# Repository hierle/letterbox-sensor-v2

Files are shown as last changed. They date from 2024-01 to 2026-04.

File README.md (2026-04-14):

# LoRaWan EU868MHz Letterbox Sensor v2
sensing letters in your letterbox via two infrared proximity sensors (HSDL9100),
sending out status via lora / lorawan, using RAK3172 (based on STM32WLE5CC) CPU/RF, powered by a CR2032 battery.

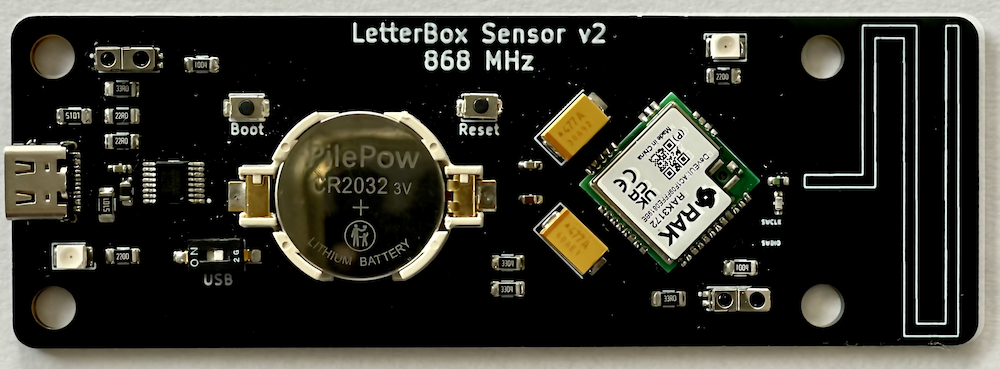
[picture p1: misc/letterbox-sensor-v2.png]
Lorawan letterbox sensor v2
<br>
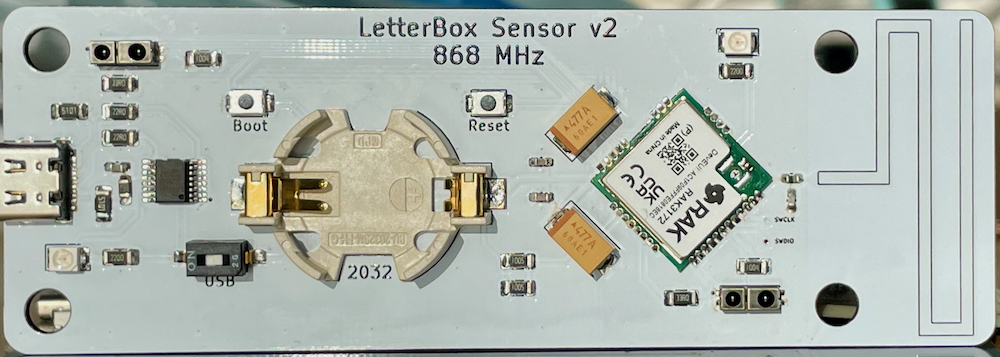
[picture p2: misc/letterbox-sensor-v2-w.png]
Lorawan letterbox sensor v2


This project was inspired by the heise ct briefkasten sensor project<br>
https://www.heise.de/ratgeber/IoT-Netz-LoRaWAN-Briefkastensensor-mit-hoher-Reichweite-selber-bauen-4417179.html<br>
https://github.com/jamct/radio-mailbox<br>
and is a direct successor of version 1: https://github.com/hierle/letterbox-sensor

Contents:
- ./PCB/ :                  kicad PCB files
- ./letterbox-sensor-v2/ :  lorawan letterbox sensor sketch
- ./misc/ :                 payload decoder, sample http integration cgi

An extended web ui by Peter is available here: https://github.com/pbiering/letterbox-sensor-web

A nice alternative software by Henrik, using Lora P2P mode is available here: https://github.com/HonkStonk/MightyMailbox

Compiled and flashed with ArduinoIDE with RAKWireless STM32 extensions

Features:
- using RAKWireless RAK3172 based on STM32WLE5CC
- deep sleep at (measured) 5uA including battery voltage divider and tantalium caps
- two proximity sensors HSDL9100
- USB-C interface for flashing and serial monitor, via FT230XS-R USB-UART
- onboard 868MHz PCB antenna after TI document http://www.ti.com/lit/an/swra227e/swra227e.pdf
- lorawan activation either ABP or OTAA
- battery voltage measurment thru voltage divider (2x 10MOhm)

Changes to v1:
- replaced ATTiny and RFM95 with RAK3172, much more CPU power and memory, much simpler code
- support for OTAA lorawan activation
- much simpler software stack, using ArduinoIDE with RAKWireless STM32 extensions and API usage
- added USB-C interface, no more special programming interface needed
- added second HSDL9100 for better physical letterbox coverage
- added two (optional) supporting tantalium caps for extended battery life
- removed temperature, as not easily avail on STM32WLE5CC / RAK API
- removed trimmers

BOM (digikey.de):

| Count | Part number | Description | Usage |
|---|---|---|---|
| 1 | RAK3172-8-SM-NI | CPU/RF-Lora  NO IPEX! | CPU/RF module |
| 2 | CS1213AGF260 | Tactile switch | Boot/Reset |
| 2 | HSDL-9100-021/024  | Proximity Sensor | Proximity sensors |
| 2 | CRGCQ1206F33R | RES 33 Ohm 1206 | Proximity sens LED | 
| 2 | CRGCQ1206F1M0 | RES 1M Ohm 1206 | Proximity sens diode |
| 1 | BU2032SM-FH-GTR | CR2032 COIN CELL HOLDER | Battery |
| 2 | TAJE477M010RNJ | CAP tant 470u | Battery supporting caps  |
| 1 | LQG18HN1N8S00D | IND 1.8NH 0603 | Antenna matching |
| 1 | GRM1885C1H2R7CA01D | CAP 2.7PF 0603 | Antenna matching |
| 3 | GRM188R72A104KA35D | CAP CER 0.1u 0603 | Suppressor caps |
| 2 | GRM188D71A106KA73D | CAP CER 10u 0603 | Suppressor caps |
| 1 | RAHUC31AUTR | USB-C connector | USB |
| 1 | FT230XS-R | FTDI USB Serial UART | USB UART |
| 1 | MI0805K601R-10 | Ferrite bead 0805 | USB power |
| 2 | AC1206FR-075K1L | RES 5.1k Ohm 1206 | USB power sens |
| 2 | CRGCQ1206F22R | RES 22 Ohm 1206 | USB lines |
| 1 | GRM188R72A104KA35D | DIP switch | Power switch USB/Battery |
| 2 | AA3528LSECKT/J4 | LED orange | Status/USB status |
| 2 | CRGCQ1206F220R | RES 220 Ohm 1206 | Status LEDs |
| 2 | RC1206FR-0710ML | RES 10M Ohm 1206 | Battery voltage measure  |

RAK3172 documentation:

https://docs.rakwireless.com/Product-Categories/WisDuo/RAK3172-Module/Overview/

How to compile:

Follow the instructions on<br>
https://docs.rakwireless.com/Product-Categories/WisDuo/RAK3172-Module/Quickstart/<br>
in short:<br>
- install ArduinoIDE from arduino.cc
- add the following URL to the boards manager URLs section in preferences:
https://raw.githubusercontent.com/RAKWireless/RAKwireless-Arduino-BSP-Index/main/package_rakwireless.com_rui_index.json
- install the "RAKwireless RUI STM32 Boards" from the Boards Manager
- select "WisDuo RAK3172 Evaluation Board" board
- on Mac you might need to install pyserial: sudo pip3 install pyserial
- on Linux you might need to install python3-pyserial
- connect the board, make sure it's powered on (DIP switch)
- select the corresponding serial port
- open the sketch folder
- adjust config.h and lorawan.h
- compile and flash

For configuration adjust config.h and lorawan.h

config.h:
- PERIOD: the time intervall you want the sensor to send it's data, in minutes, default is 30 minutes
- THRESHOLD: the threshold for the sensor readings (empty/full), can later be "overwritten" in e.g. HTML integration
- USE_OTAA: if true, OTAA will be used instead of ABP, so we do not have to worry about frame counters after reset / battery change
- DATARATE and TXPOWER: adjust to your needs, your packets should be reliably received, w/o wasting to much power
- see also the comments for each entry in config.h

lorawan.h:
- set your lorawan keys for either ABP or OTAA
- OTAA_APPEUI or JOINEUI is only needed to select a specific JOIN server, in private networks can be set to any value

Additional notes:
- you will need a *DATA* USB-C cable, a charging only cable will not work, as it's missing the data pins ;-)
- the DIP switch allows to power the device directly from USB, but when using the battery in production environment (letterbox), it should be switched off, not to waist power on the FT230 USB-UART chip

Letterbox sensor v2 lorawan payload package byte structure:

|byte| 0 |  1 2 | 3 4 | 5 6 | 7 |
|----|---|---|---|---|---|
| |0x00=empty|battery |sensor1|sensor2|threshold|
| |0xFF=full |voltage |raw |raw | |

Todos:
- read battery voltage and temperature from STM32
- see sections 3.18.1 and 3.18.3 in: https://www.st.com/resource/en/datasheet/stm32wle5c8.pdf

Have fun!

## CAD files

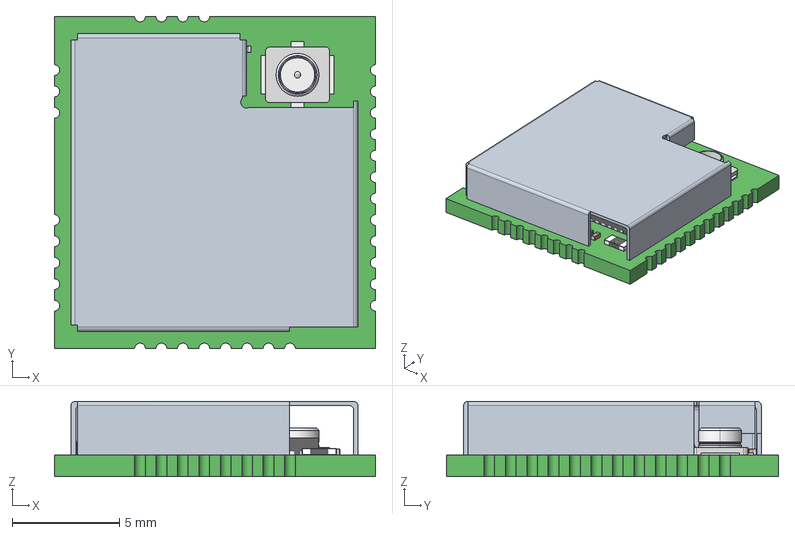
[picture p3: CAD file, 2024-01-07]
PCB/3D/RAK3172.step
15.0 x 15.5 x 3.51 mm
0201_SMD_Capacitor x 36
Extruded
R0201 x 7
RES_1005-0402 x 3
QFN48_7x7
NT2016SA
C0402 x 4
crystal_rtf2012
D030A-そ敖裔

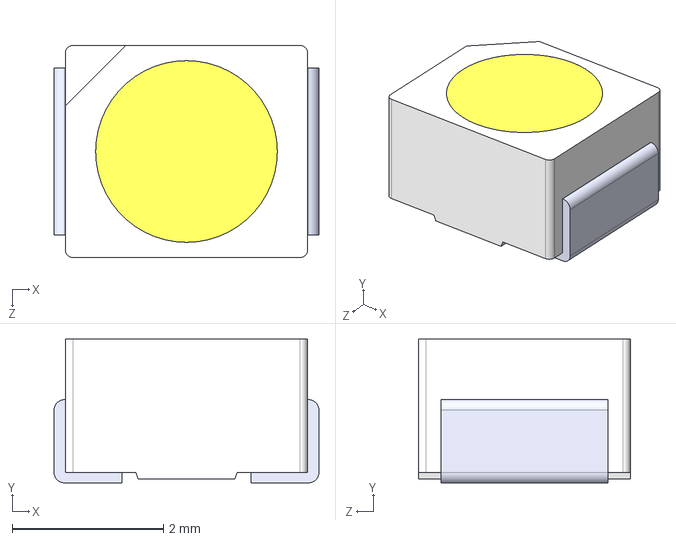
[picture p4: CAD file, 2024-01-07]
PCB/3D/OF-SMD3528WC--3DModel-STEP-269445.STEP
3.50 x 1.90 x 2.80 mm

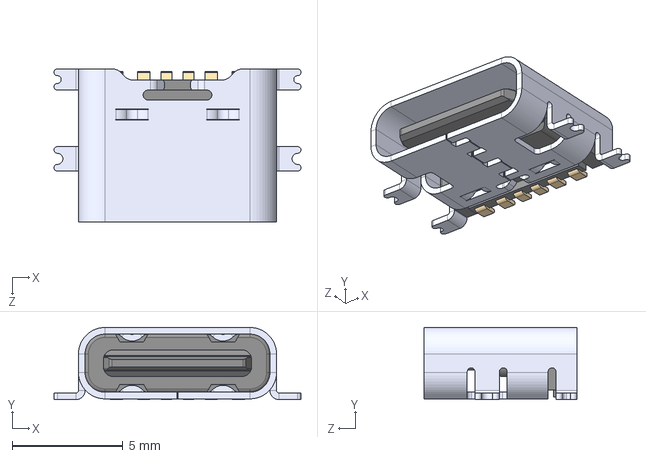
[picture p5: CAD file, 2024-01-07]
PCB/3D/USB4135-GF-A--3DModel-STEP-269445.STEP
11.1 x 3.25 x 6.90 mm

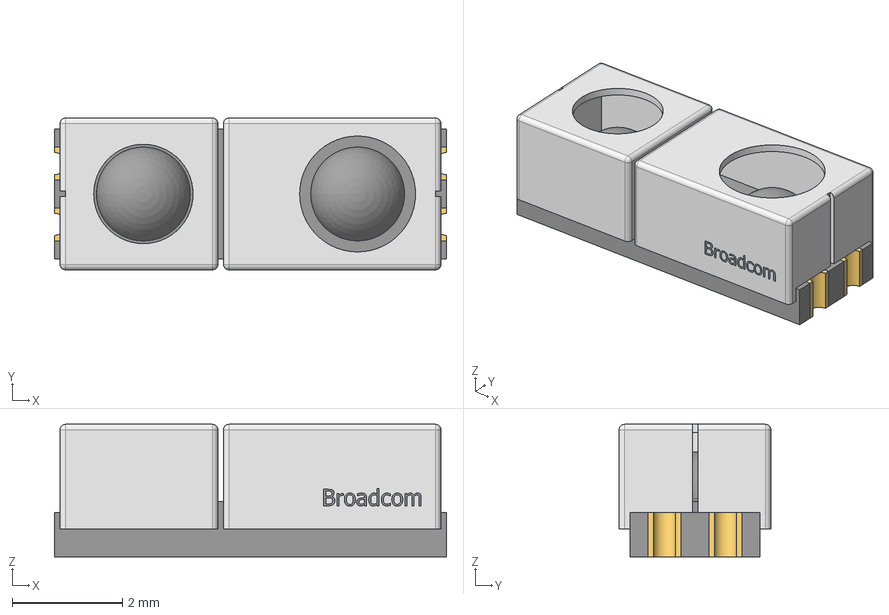
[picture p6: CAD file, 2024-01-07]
PCB/3D/Broadcom_-_HSDL-9100-021.step
7.10 x 2.75 x 2.40 mm
base
leds
terminals
name

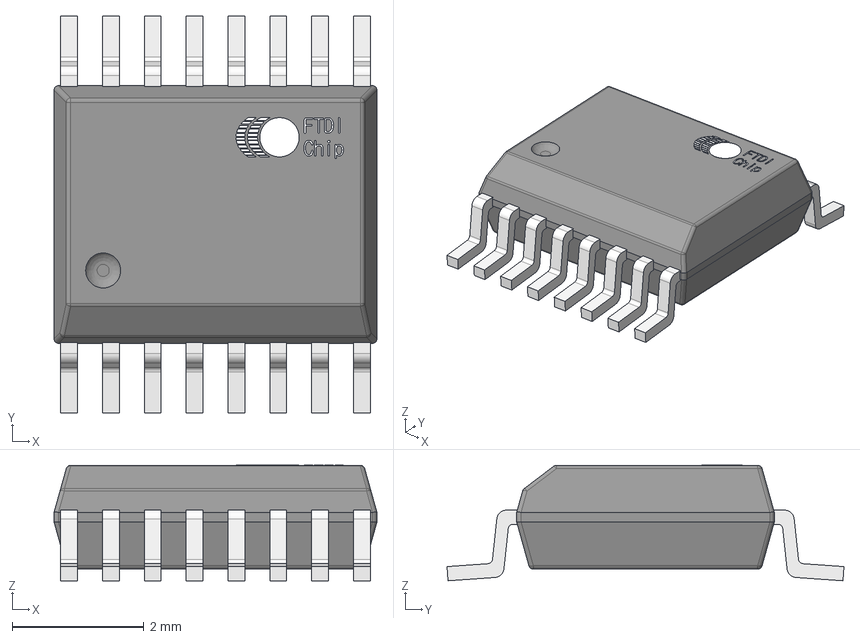
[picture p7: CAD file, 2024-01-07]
PCB/3D/FTDI_-_FT230XS-R.step
4.90 x 6.02 x 1.75 mm

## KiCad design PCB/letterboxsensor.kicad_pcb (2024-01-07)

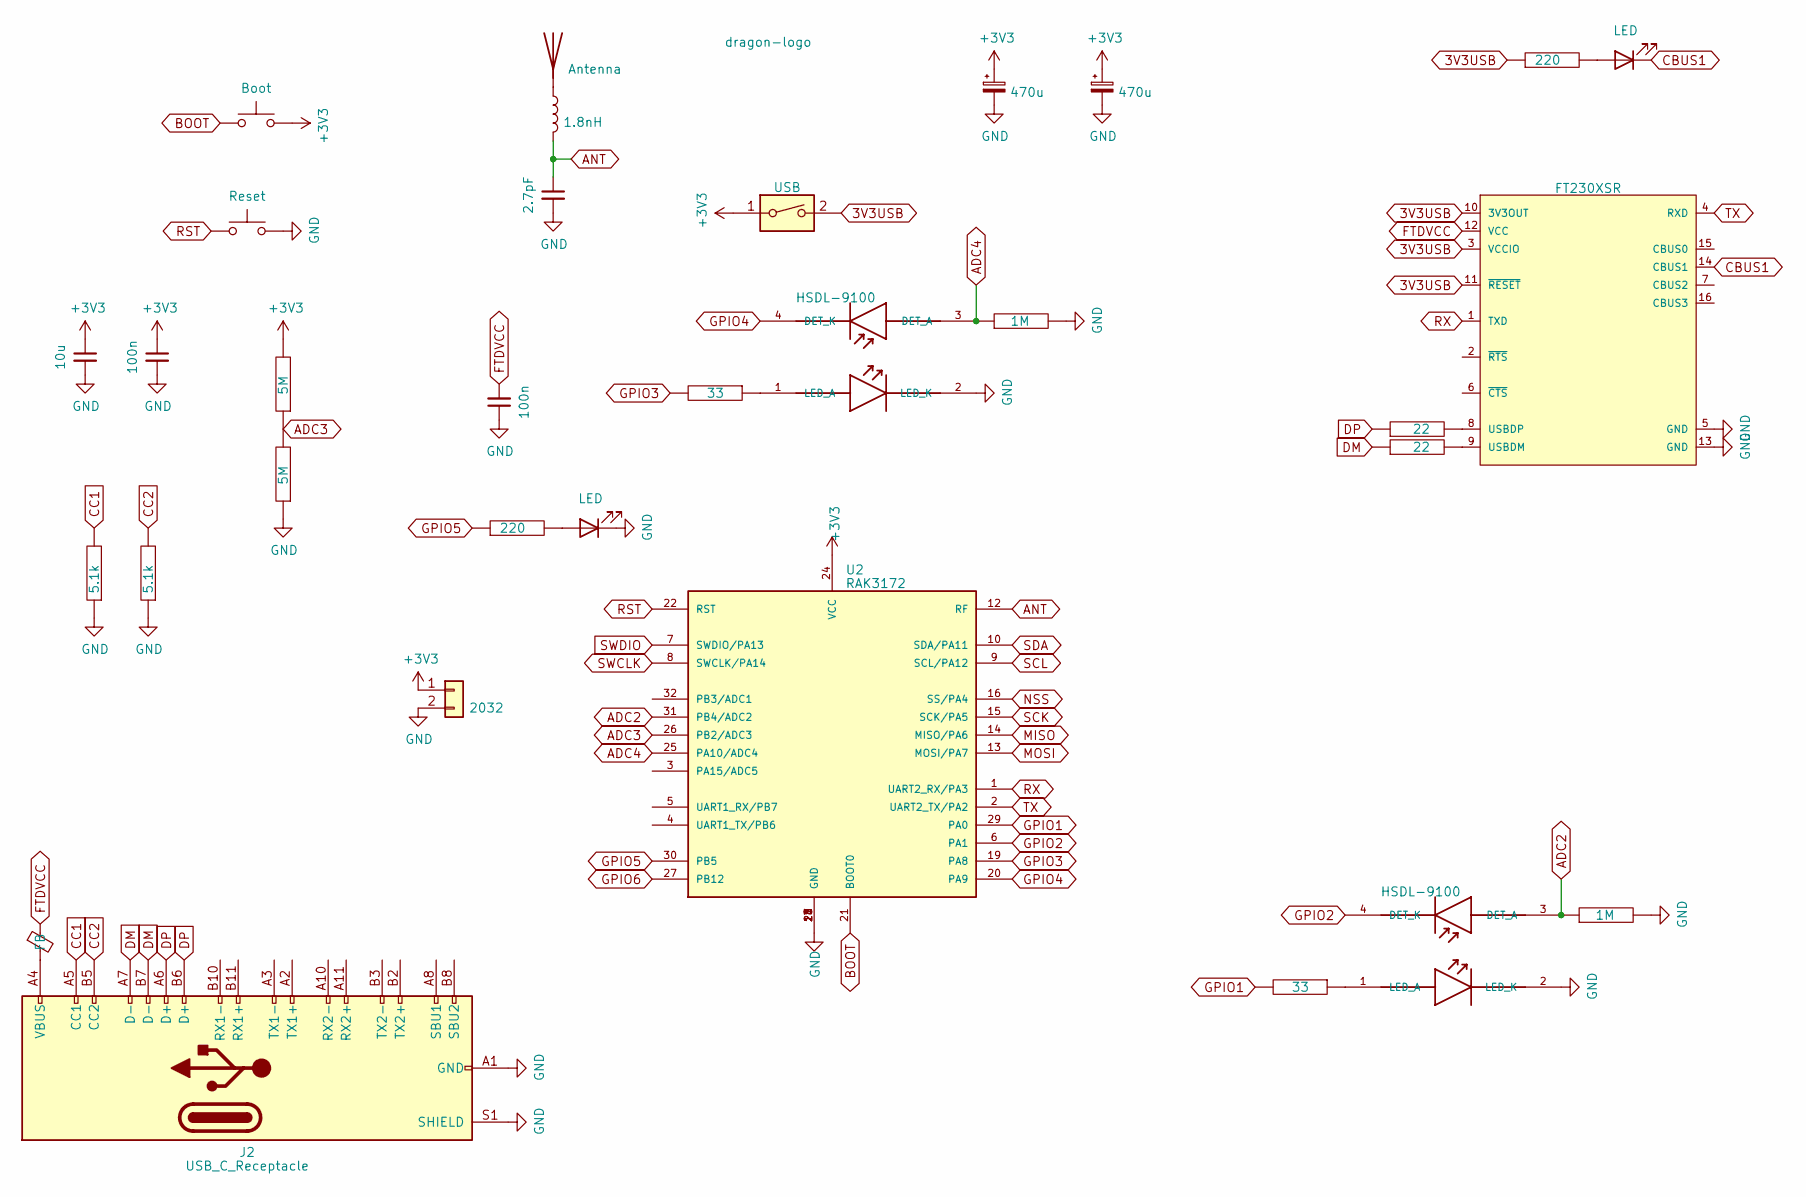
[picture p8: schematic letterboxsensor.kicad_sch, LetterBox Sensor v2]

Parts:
AE1: Antenna; TI-DN024-SL-SHORT
C1: 2.7pF; C_0603_1608Metric_Pad1.08x0.95mm_HandSolder
C2, C3: 470u; CP_EIA-7343-30_AVX-N_Pad2.25x2.55mm_HandSolder
C4, C7: 100n; C_0603_1608Metric_Pad1.08x0.95mm_HandSolder
C5: 10u; C_0603_1608Metric_Pad1.08x0.95mm_HandSolder
D1, D3: HSDL-9100; Broadcom-HSDL-9100-021-0-0-MFG
D2, D4: LED; LED_PLCC_2835_Handsoldering
DRAGON2: dragon-logo; Dragon
FB1: FB; L_0805_2012Metric_Pad1.05x1.20mm_HandSolder
J1: 2032; BatteryHolder_MPD_BU2032SM-FH_2032
J2: USB_C_Receptacle; USB_C_Receptacle_RAHUC31AUTR
JP1: USB; SW_DIP_SPSTx01_Slide_Omron_A6S-110x_W8.9mm_P2.54mm
L1: 1.8nH; L_0603_1608Metric
R1, R5: 33; R_1206_3216Metric
R2, R8: 220; R_1206_3216Metric
R4, R7: 1M; R_1206_3216Metric
R9, R10: 5.1k; R_1206_3216Metric
R11, R14: 5M; R_1206_3216Metric
R12, R13: 22; R_1206_3216Metric
SW1: Boot; SW_Push_SPST_NO_Alps_SKRK
SW2: Reset; SW_Push_SPST_NO_Alps_SKRK
U2: RAK3172
U3: FT230XSR; FTDI-SSOP-16-0-0-IPC_A; mouser part number 895-FT230XS-R; digikey description IC USB SERIAL BASIC UART 16SSOP

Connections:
3V3USB: JP1.2, R8.1, U3.3 (VCCIO), U3.10 (3V3OUT), U3.11 (~RESET)
+3V3: C2.1, C3.1, C4.1, C5.1, J1.1, JP1.1, R11.2, SW1.2, U2.24 (VCC)
ADC2: D3.3 (DET_A), R7.1, U2.31 (PB4/ADC2)
ADC3: R11.1, R14.2, U2.26 (PB2/ADC3)
ADC4: D1.3 (DET_A), R4.1, U2.25 (PA10/ADC4)
ANT: C1.1, L1.2, U2.12 (RF)
BOOT: SW1.1, U2.21 (BOOT0)
CBUS1: D4.1 (K), U3.14 (CBUS1)
CC1: J2.A5 (CC1), R10.2
CC2: J2.B5 (CC2), R9.2
DM: J2.A7 (D-), J2.B7 (D-), R13.1
DP: J2.A6 (D+), J2.B6 (D+), R12.1
FTDVCC: C7.2, FB1.1, U3.12 (VCC)
GND: C1.2, C2.2, C3.2, C4.2, C5.2, C7.1, D1.2 (LED_K), D2.1 (K), D3.2 (LED_K), J1.2, J2.A1 (GND), J2.A12 (GND), J2.B1 (GND), J2.B12 (GND), J2.S1 (SHIELD), R4.2, R7.2, R9.1, R10.1, R14.1, SW2.2, U2.11 (GND), U2.17 (GND), U2.18 (GND), U2.23 (GND), U2.28 (GND), U3.5 (GND), U3.13 (GND)
GPIO1: R5.2, U2.29 (PA0)
GPIO2: D3.4 (DET_K), U2.6 (PA1)
GPIO3: R1.2, U2.19 (PA8)
GPIO4: D1.4 (DET_K), U2.20 (PA9)
GPIO5: R2.1, U2.30 (PB5)
GPIO6: U2.27 (PB12)
MISO: U2.14 (MISO/PA6)
MOSI: U2.13 (MOSI/PA7)
NSS: U2.16 (SS/PA4)
unnamed: AE1.1 (A), L1.1
unnamed: D1.1 (LED_A), R1.1
unnamed: D2.2 (A), R2.2
unnamed: D3.1 (LED_A), R5.1
unnamed: D4.2 (A), R8.2
unnamed: FB1.2, J2.A4 (VBUS), J2.A9 (VBUS), J2.B4 (VBUS), J2.B9 (VBUS)
unnamed: R13.2, U3.9 (USBDM)
unnamed: R12.2, U3.8 (USBDP)
RST: SW2.1, U2.22 (RST)
RX: U2.1 (UART2_RX/PA3), U3.1 (TXD)
SCK: U2.15 (SCK/PA5)
SCL: U2.9 (SCL/PA12)
SDA: U2.10 (SDA/PA11)
SWCLK: U2.8 (SWCLK/PA14)
SWDIO: U2.7 (SWDIO/PA13)
TX: U2.2 (UART2_TX/PA2), U3.4 (RXD)

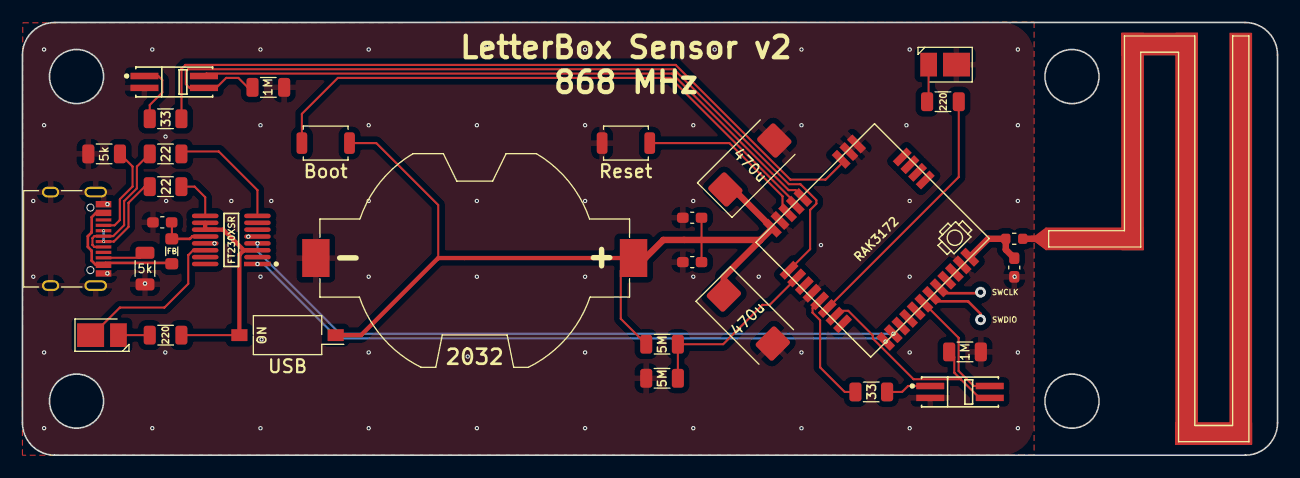
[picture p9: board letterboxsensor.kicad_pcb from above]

Board: 2 copper layers, 116.0 x 40.0 mm, 33 parts (1 on the bottom side), 30 nets.

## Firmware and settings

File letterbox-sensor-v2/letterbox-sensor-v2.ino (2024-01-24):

// 
// letterbox-sensor-v2.ino
//

#include <Arduino.h>
#include "config.h"
#include "pins.h"
#include "lorawan.h"

void setup() {

  // set up serial line
  Serial.begin(115200);
  delay(1000);
  Serial.println("-------------------------");
  Serial.println("Letterbox sensor v2");
  Serial.printf("Firmware Version: %s\r\n", api.system.firmwareVersion.get().c_str());
  Serial.printf("CLI Version: %s\r\n", api.system.cliVersion.get().c_str());
  Serial.printf("API Version: %s\r\n", api.system.apiVersion.get().c_str());
  Serial.printf("Model ID: %s\r\n", api.system.modelId.get().c_str());
  Serial.printf("Hardware ID: %s\r\n", api.system.chipId.get().c_str());
  Serial.println("-------------------------");

  // set pinmodes
  pinMode(statusled, OUTPUT);
  pinMode(irled1, OUTPUT);
  pinMode(irled2, OUTPUT);
  pinMode(irdiode1, OUTPUT);
  pinMode(irdiode2, OUTPUT);
  pinMode(irsens1, INPUT);
  pinMode(irsens2, INPUT);

  // init lorawan
  lorawan_init();

  // set low power mode
  if (!api.system.lpm.set(1)) {	Serial.println("Set low power mode failed! \r\n");}

  // ADC mode
  //udrv_adc_set_mode(UDRV_ADC_MODE_3_3);

  // blink led once on startup
  digitalWrite(statusled,HIGH);
  delay(50);
  digitalWrite(statusled,LOW);

	// create timer
	api.system.timer.create(RAK_TIMER_0, sensor_handler, RAK_TIMER_PERIODIC);
  // start timer
	api.system.timer.start(RAK_TIMER_0, PERIOD*60*1000, NULL);

  // get and send sensor values on boot
	sensor_handler(NULL);
}

// read sensor values and send lorawan package
void sensor_handler(void *) {

  // variables
  unsigned int s1 = 0; // sensor#1
  unsigned int s2 = 0; // sensor#2
  unsigned int bat = 0; // battery

  // data buffer
  uint8_t data_length = 8;
  uint8_t data[data_length];

  // measure sensor #1
  digitalWrite(irled1,HIGH);
  digitalWrite(irdiode1,HIGH);
  delay(10);
  for(int i = 0 ; i <3 ; i++){
    delay(25);
    s1 += analogRead(irsens1);
  }
  s1=s1/3;
  digitalWrite(irled1,LOW);
  digitalWrite(irdiode1,LOW);
  Serial.printf("Sensor#1: %d\r\n", s1);

  // measure sensor #2
  digitalWrite(irled2,HIGH);
  digitalWrite(irdiode2,HIGH);
  delay(10);
  for(int i = 0 ; i <3 ; i++){
    delay(25);
    s2 += analogRead(irsens2);
  }
  s2=s2/3;
  digitalWrite(irled2,LOW);
  digitalWrite(irdiode2,LOW);
  Serial.printf("Sensor#2: %d\r\n", s2);

  // letterbox full/empty
  if((s1 > THRESHOLD)||(s2 > THRESHOLD)) { data[0] = 0xFF; }
  else { data[0] = 0x00; }

  // battery voltage from external voltage divider
  analogReadResolution(12);
  delay(25);
  bat=analogRead(vdiv);
  //Serial.printf("Voltage12b: %d\r\n", bat);
  //bat = 1750 + (bat - 1235)*10; // 2x 3.3MOhm
  bat = 1550 + (bat - 1040)*8; // 2x 10MOhm
  Serial.printf("Voltage: %d\r\n", bat);
  analogReadResolution(10);

  // battery
  data[1] = (bat & 0xFF);
  data[2] = ((bat >> 8) & 0xFF);

  // sensor#1
  data[3] = (s1 & 0xFF);
  data[4] = ((s1 >> 8) & 0xFF);

  // sensor#2
  data[5] = (s2 & 0xFF);
  data[6] = ((s2 >> 8) & 0xFF);

  // threshold
  data[7] = THRESHOLD;

  // temperature N/A for now
  //data[8] = readTemp();

  Serial.println("-------------------------");

  // send data via lorawan
  lorawan_send(data, data_length);

}


void loop(){
  // destroy this busy loop and use a timer instead,
  // so that the system thread can auto enter low power mode by api.system.lpm.set(1)
  api.system.scheduler.task.destroy();
}

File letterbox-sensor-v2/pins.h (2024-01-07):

//
// pins.h
//

// pin mappings

// status led
#define statusled PB5

// sensor #1
// ir-led of proximity sensor#1 (invisible)
#define irled1 PA0
// power in for diode in proximity sensor
#define irdiode1 PA1
// adc pin (connect to output of sensor)
#define irsens1 PB4

// sensor #2
// ir-led of proximity sensor#1 (invisible)
#define irled2 PA8
// power in for diode in proximity sensor
#define irdiode2 PA9
// adc pin (connect to output of sensor)
#define irsens2 PA10

// adc pin battery voltage divider
#define vdiv PB2
